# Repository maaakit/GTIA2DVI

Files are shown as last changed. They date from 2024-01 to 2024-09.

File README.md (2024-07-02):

# GTIA2DVI

**GTIA2DVI** jest prototypem urządzenia umożliwiającego wyświetlanie obrazu cyfrowego w standardzie DVI przez
ośmiobitowe komputery Atari. Komputery te były produkowane w czasach gdy telewizja cyfrowa nie była publicznie dostępna 
przez co są zdolne generowac obraz jedynie w analogowych systemach PAL / NTSC. Większośc nowych telewizorów nie jest 
w stanie wyświetlić obrazu generowaniego przez Atari w zadowalającej jakosci.
Powstało wiele urządzeń oraz modów toru video Atari w mniejszym lub większym stopniu poprawiajacych jakość obrazu.
Jednak wszystkie te rozwiązania polegaja na zmianie parametrów obrazu analogowego a następnie jego digitalizację i 
konwersję do obrazu cyfrowego.

Ten projekt jest próbą rozwiązania problemu w pełni w domenie cyfrowej. Sercem projektu jest mikrokontroler RP2040 i biblioteka [PicoDVI](https://github.com/Wren6991/PicoDVI) dzięki której może on generować obraz DVI. GTIA2DVI w sposób software'owy ale z wykorzystaniem udostępnianego przez
RP2040 hardweru tj: DMA, PIO, Interpolator realizuje dekodowanie sygnałów generowanych przez Atari oraz tworzenie obrazu.

## Szczegóły techniczne

Obraz w komputerach Atari jest generowany przez układy specializowane ANTIC / GTIA. 
Ten drugi układ jest odpowiedzialny z generowanie sygnałów które są następnie przetwarzane przez układy analogowe
w obraz w systemie PAL/NTSC. Z dostępnych w internecie materiałów można wywnioskować że wszystkie sygnały wyjściowe GTIA
składające się na obraz wideo na pinach tego układu są cyfrowe. Są to następujące:

| nazwa sygnału | pin GTIA | opis |
|---|---|---|
| OSC | 28 | sygnał zegarowy synchronizujący pixele w trybie hires |
| CSYNC | 25 | sygnał synchronizacji pionowej i poziomej |
| LUM0 - LUM3 | 31,22,23,24 | 4-bitowy równoległa linia prezentująca wartość jasności pixela |
| PAL | 16 | sygnał zegara odpowiadającego za kodowanie koloru w systemie PAL |
| COLOR | 21 | wartość koloru okreeślona przez przesunięcie fazowe tego sygnału względem PAL |

Celem projektu jest generowanie obrazu cyfrowego na podstawie wyżej wymienionych sygnałów.

## Budowanie projektu

Należy mieć skonfigurowane środowisko SDK dla RP2040 (patrz https://datasheets.raspberrypi.com/pico/getting-started-with-pico.pdf)

Projekt mozna zbudwać posługując się IDE (np. Visual Studio Code)

lub z linii komend:

```shell

cd software
mkdir build
cd build
cmake -DCMAKE_BUILD_TYPE=Release ..
make

```

Wynikiem procesu budowania jest plik: `build/gtia2dvi/gtia2dvi.uf2` który nalezy wgrać do RP2040.

Uwaga! Jedynie plik zbudowane w `BUILD_TYPE=Release` zapewniają poprawne działanie programu

## Uruchomienie

Po zamontowaniu urządzenia w Atari sygnał DVI będzie dostępny automatycznie. W podstawowej konfiguracji generowany jest 
sygnał monochroamtyczny w odcieniach szarości. 
Dekodowanie sygnału **chroma** jest w fazie eksperymentalnej i może zostać włączone z poziomu menu po uprzednim skalibrowaniu.

Urządzenie posiada 3 przyciski:

* **RESET** służący do resetowania
* **BTN_A** słuzący do aktywacji menu podczas restartu oraz do wybierania opcji menu. Poza menu przełącza tryb wyświetlania mono / color
* **BTN_B** służacy do aktywacji wybranej opcj menu. Poza menu pełni funkcję stopklatki (zatrzymuje odświerzanie obrazu Atari)

Aby wejść do menu systemowego należy trzymac wciśnięty przycisk **BTN_A** w trakcie restartu urządzenia (za pomocą przycisku reset)

## Opcje menu

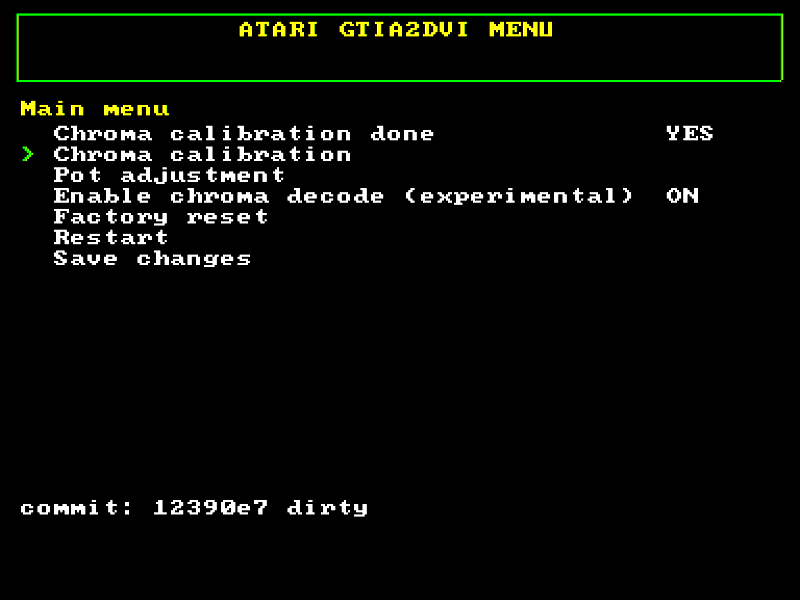
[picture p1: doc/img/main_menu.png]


* Informacja o statusie kalibracji
* [Kalibracja sygnału chroma](#kalibracja-sygnału-chroma)
* [Procedura ustawiania potencjometru CADJ](#ustawienie-potencjometru-CADJ)
* Włączanie / wyłączanie dekodowania
* Przywrócenie do ustawień fabrycznych
* Wyjście z menu i powrót do normalnego trybu
* Zapisanie wprowadzonych zmian

## Kalibracja sygnału chroma

Należy uruchomić Atari Basic i załadować program CALSCR którego listing znajduje się w folderze `atari`
Program wyświetla obraz służący do kalibracji. 

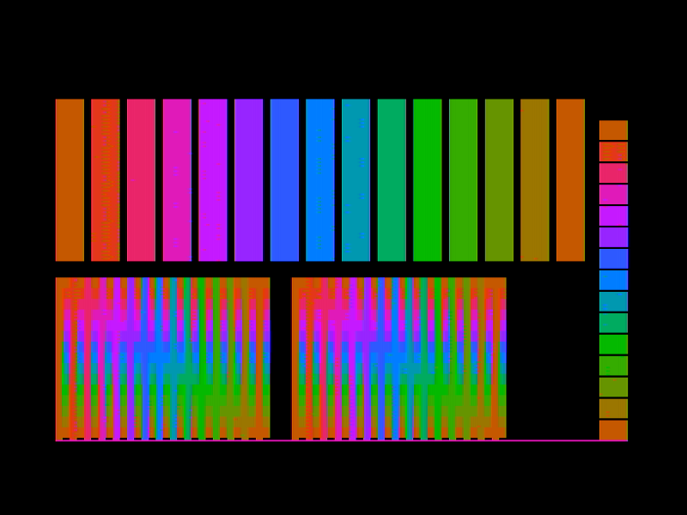
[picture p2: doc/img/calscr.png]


Gdy jego tworzenie zostanie zakończone należy przejść do menu GTIA2DVI.
Następnie wybrać opcję `Chroma Calibration` i ją potwierdzić.

W czasie kalibracji prezentowany jest na żywo aktualny postęp budowania mapy kolorów.
Proces składa się zdwóch przebiegów i trwa ok. 95 sekund. Po tym czasie urządzenie zapisze zarejestrowane mapy kolorów 
w automatycznie pamięci FLASH i automatycznie się zrestartuje.

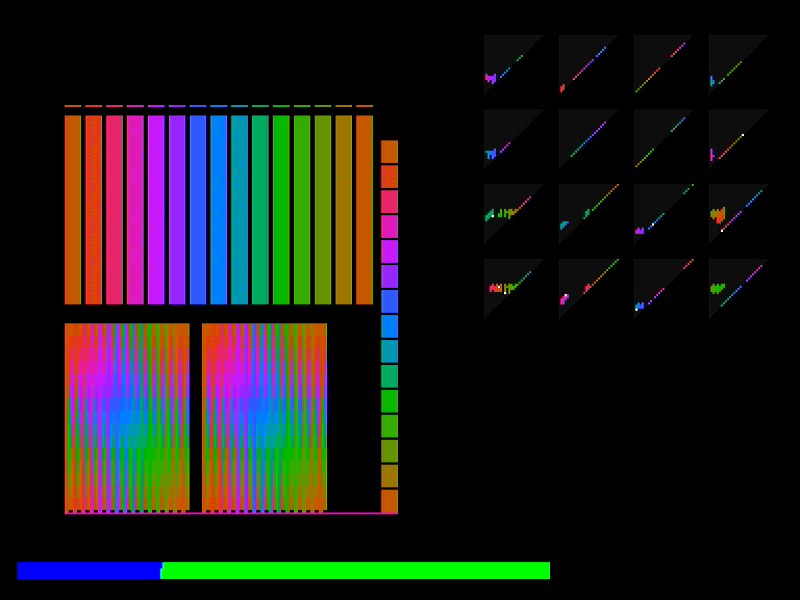
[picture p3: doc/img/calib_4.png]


## Ustawienie potencjometru CADJ

W pewnych przypadkach aby uzyskać dobry rezultat kalibracji niezbędne jest dostrojenie potencjometru CADJ.
W trakcie tego procesu Atari powinno wyświetlać ten sam obraz jak w procesie kalibracji (CALSCR).
Należy znaleźć takie położenie w którym na obrazie nie występują żółte kropki oraz ilość szarych jest jak najmniejsza.
Po zakończeniu regulacji należy przycisnąć RESET na płytce GTIA2DVI

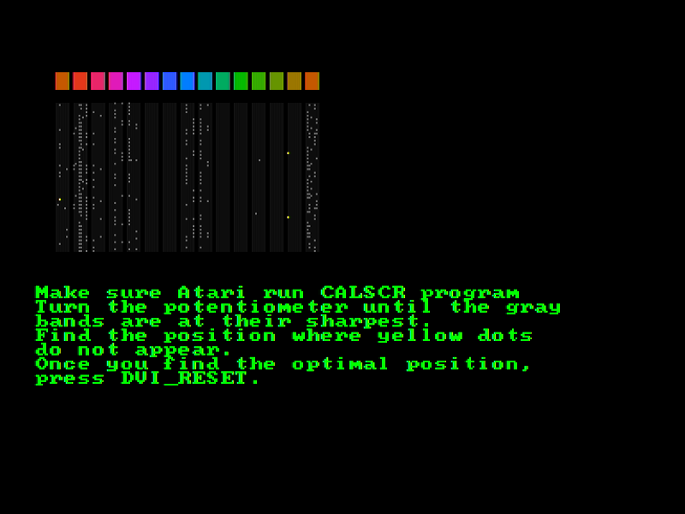
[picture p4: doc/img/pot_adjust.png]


## Dodatkowe wskazówki

Najlepszą jakość wyświetlanego koloru można osiągnąc na płytach które zapewniają niski poziom szumów i zakłóceń sygnałów.
Dodatkowe rozszerzenia np. U1MB, SIDE2 generują zauważalne zakłócenia w wyświetlanym kolorze
Pozytywny wpływ na generowany obraz mogą mieć:
* Zamiana dławika L37 na rezystor 470ohm
* Wymiana kondensatora C50 na nowy o niskim ESR
* Wymina potencjometru CADJ (R38) na precyzyjny wieloobrotowy
* zastosowanie Static RAM (niezweryfikowane)

## Troubleshooting

1) **Obraz DVI nie jest wyświetlany** należy:
   * wyłączyć Atari i zdemontowac GTIA2DVI
   * zweryfikować wszystkie połączenia
   * wgrać jeden z przykładowych programów z repozytorium PicoDVI (https://github.com/Wren6991/PicoDVI)

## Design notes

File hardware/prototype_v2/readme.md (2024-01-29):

# Lista elementów

| symbol | nazwa | wartość |
|---|---|---|
| C1 - C3  | kondensator | 100nF |
| R1 - R8  | rezystor | 270R |
| R9 - R14 | nie montować | |
| X1 | Raspberry Pi Pico | |
| IC2 | 74AC541 | |
| IC4P | podstawka 40pin | |
| IC5P | pin header 2x20 | |
| DVI | złącze DVI lub kompatybilne | |
| SWITCH | 3 mikrowłączniki do masy | |

## procedura pierwszego uruchomiania

1) Po zmontowaniu zweryfikować wszystkie połączenia
2) Nie montować GTIA i nie umieszczać modułu na płycie Atari
3) Podpiąć kablem usb do PC trzymając wciśnięty przycisk BOOTSEL
4) wgrać wsad gtia2dvi.uf2
5) podłączyć kablem do TV/monitora i uruchomić menu konfiguracyjne (trzymahąc wciśnięty BTN_A zresetowac moduł)
6) po prawidłowym zweryfikowaniu wyświetlanego obrazu odłączyć wszystkie połączenia
7) zamontować GTIA
8) podłączyć do płyty Atari
9) zweryfikować połączenia i uruchomić Atari

**Uwaga !**
To jest urządzenie DIY. Sam odpowiadasz za jego prawidłowe zmontowanie, uruchomienie i wszystkie szkody które może wyrządzić!

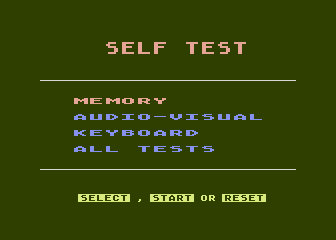
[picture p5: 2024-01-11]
software/gtia2dvi/images/atari001.png

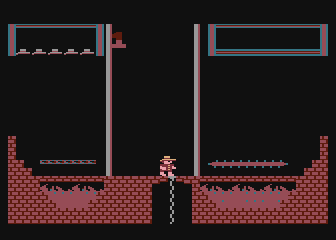
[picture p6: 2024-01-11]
software/gtia2dvi/images/atari003.png

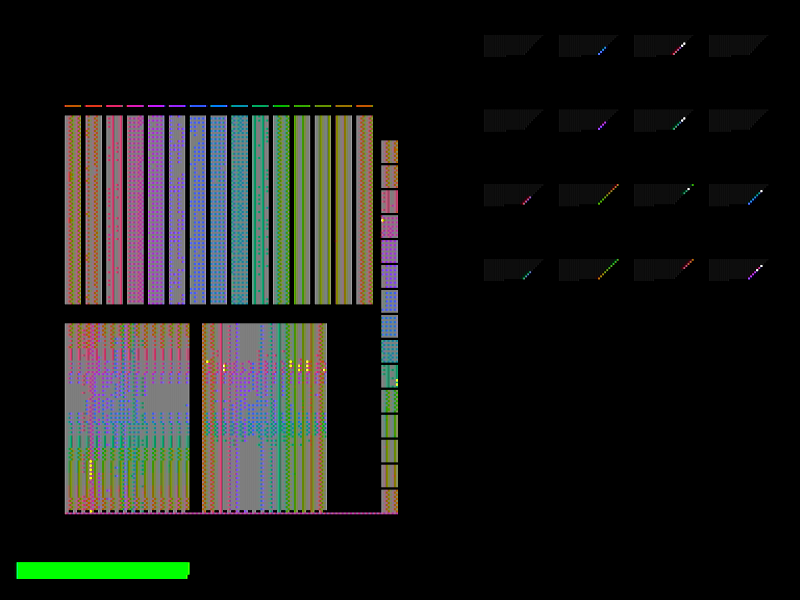
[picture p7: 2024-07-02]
doc/img/calib_2.png

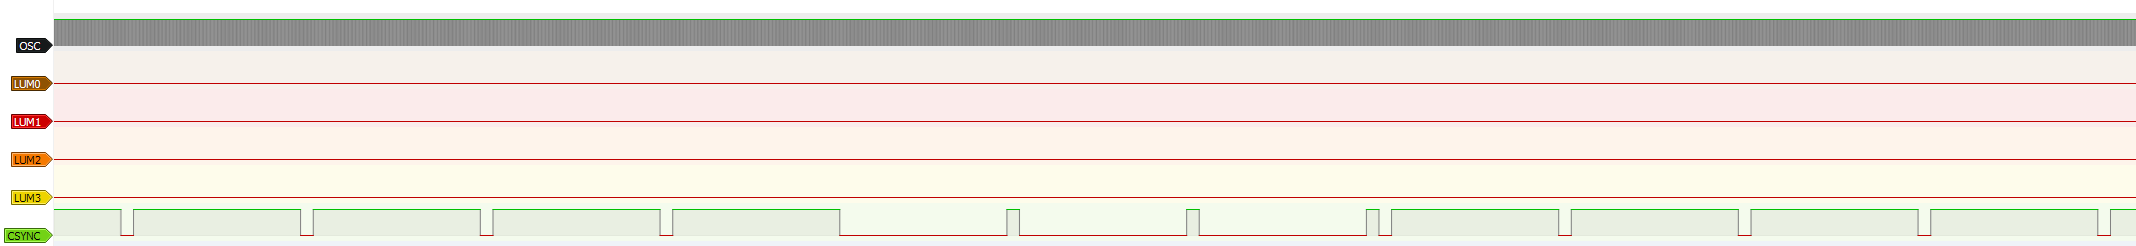
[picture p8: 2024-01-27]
luma_signals.png

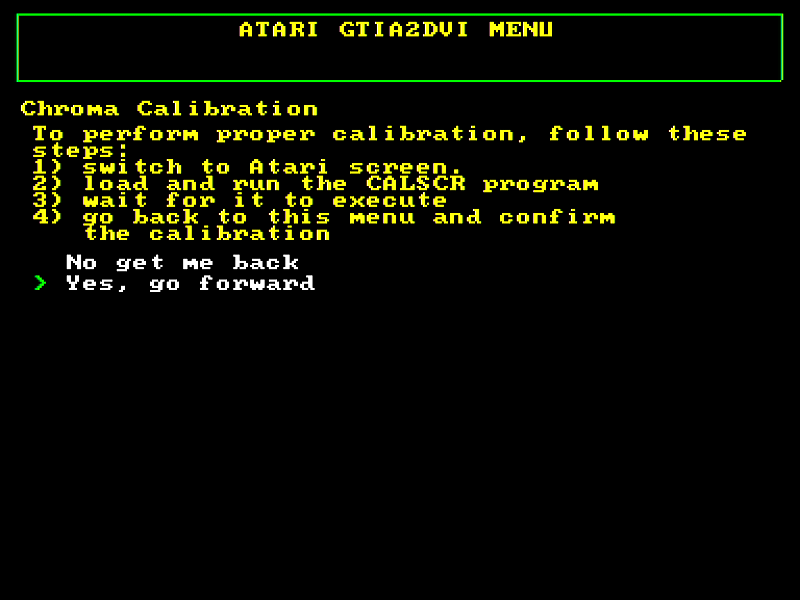
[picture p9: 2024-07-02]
doc/img/calib_confirm.png

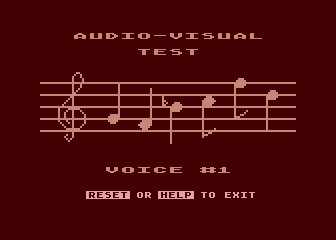
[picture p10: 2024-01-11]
software/gtia2dvi/images/atari002.png

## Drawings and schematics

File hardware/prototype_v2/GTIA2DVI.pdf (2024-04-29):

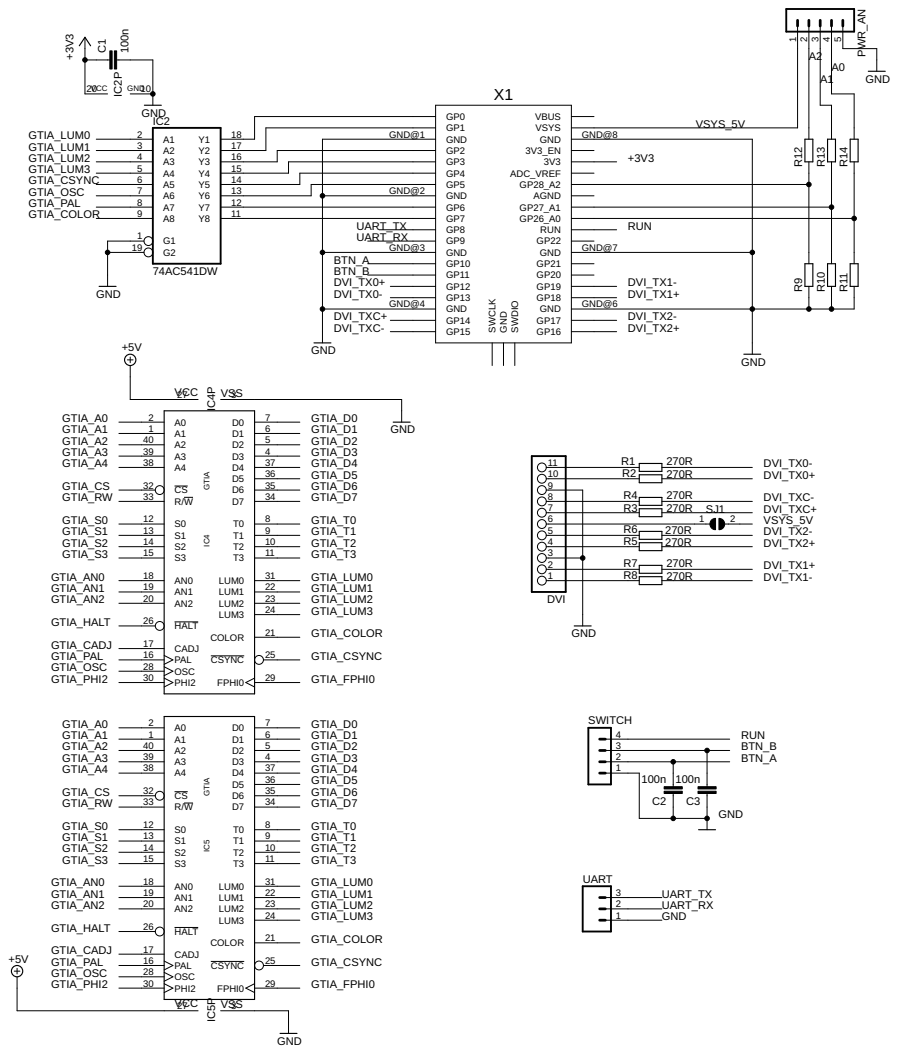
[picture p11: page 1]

UART_TX UART_RX | RUN

BTN_A BTN_B DVI_TX0+ DVI_TX0- | DVI_TX1-DVI_TX1+

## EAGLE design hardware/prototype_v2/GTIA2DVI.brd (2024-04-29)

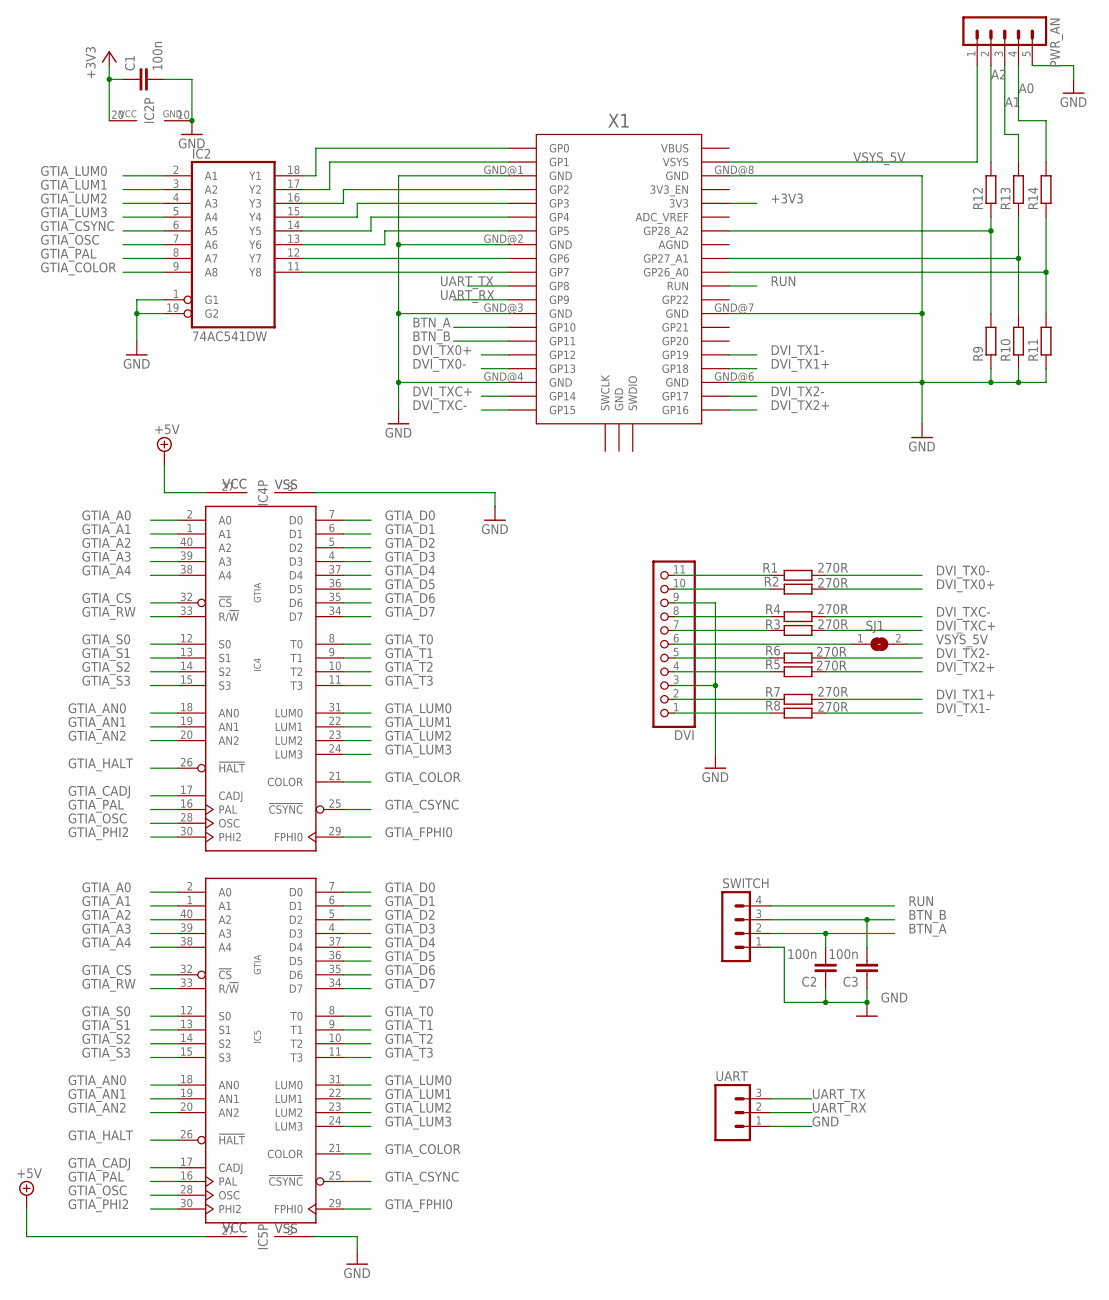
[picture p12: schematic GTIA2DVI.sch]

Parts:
C1, C2, C3: 100n; C0805
DVI: PINHD-1X11; 1X11
IC2: 74AC541DW; SO20W
IC4, IC5: GTIA; DIL40
PWR_AN: MA05-1
R1, R2, R3, R4, R5, R6, R7, R8: 270R; M0805
R9, R10, R11, R12, R13, R14: R-EU_M0805; M0805
SJ1: SJ
SWITCH: MA04-1
UART: MA03; 03P
X1: RPI_PICO_IG-TH; RPI_PICO_TH

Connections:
+3V3: C1.1, IC2.20 (VCC), X1.3V3
+5V: IC4.27 (VCC), IC5.27 (VCC)
A0: PWR_AN.4, R14.2
A1: PWR_AN.3, R13.2
A2: PWR_AN.2, R12.2
BTN_A: C2.2, SWITCH.2, X1.GP10
BTN_B: C3.2, SWITCH.3, X1.GP11
DVI_TX0+: R2.2, X1.GP12
DVI_TX0-: R1.2, X1.GP13
DVI_TX1+: R7.2, X1.GP18
DVI_TX1-: R8.2, X1.GP19
DVI_TX2+: R5.2, X1.GP16
DVI_TX2-: R6.2, X1.GP17
DVI_TXC+: R3.2, X1.GP14
DVI_TXC-: R4.2, X1.GP15
GND: C1.2, C2.1, C3.1, DVI.3, DVI.9, IC2.1 (G1), IC2.10 (GND), IC2.19 (G2), IC4.3 (VSS), IC5.3 (VSS), PWR_AN.5, R9.1, R10.1, R11.1, SWITCH.1, UART.1, X1.GND@1 (GND), X1.GND@2 (GND), X1.GND@3 (GND), X1.GND@4 (GND), X1.GND@6 (GND), X1.GND@7 (GND), X1.GND@8 (GND)
GP0: IC2.18 (Y1), X1.GP0
GP1: IC2.17 (Y2), X1.GP1
GP2: IC2.16 (Y3), X1.GP2
GP3: IC2.15 (Y4), X1.GP3
GP4: IC2.14 (Y5), X1.GP4
GP5: IC2.13 (Y6), X1.GP5
GP6: IC2.12 (Y7), X1.GP6
GP7: IC2.11 (Y8), X1.GP7
GTIA_A0: IC4.2 (A0), IC5.2 (A0)
GTIA_A1: IC4.1 (A1), IC5.1 (A1)
GTIA_A2: IC4.40 (A2), IC5.40 (A2)
GTIA_A3: IC4.39 (A3), IC5.39 (A3)
GTIA_A4: IC4.38 (A4), IC5.38 (A4)
GTIA_AN0: IC4.18 (AN0), IC5.18 (AN0)
GTIA_AN1: IC4.19 (AN1), IC5.19 (AN1)
GTIA_AN2: IC4.20 (AN2), IC5.20 (AN2)
GTIA_CADJ: IC4.17 (CADJ), IC5.17 (CADJ)
GTIA_COLOR: IC2.9 (A8), IC4.21 (COLOR), IC5.21 (COLOR)
GTIA_CS: IC4.32 (!CS), IC5.32 (!CS)
GTIA_CSYNC: IC2.6 (A5), IC4.25 (!CSYNC), IC5.25 (!CSYNC)
GTIA_D0: IC4.7 (D0), IC5.7 (D0)
GTIA_D1: IC4.6 (D1), IC5.6 (D1)
GTIA_D2: IC4.5 (D2), IC5.5 (D2)
GTIA_D3: IC4.4 (D3), IC5.4 (D3)
GTIA_D4: IC4.37 (D4), IC5.37 (D4)
GTIA_D5: IC4.36 (D5), IC5.36 (D5)
GTIA_D6: IC4.35 (D6), IC5.35 (D6)
GTIA_D7: IC4.34 (D7), IC5.34 (D7)
GTIA_FPHI0: IC4.29 (FPHI0), IC5.29 (FPHI0)
GTIA_HALT: IC4.26 (!HALT), IC5.26 (!HALT)
GTIA_LUM0: IC2.2 (A1), IC4.31 (LUM0), IC5.31 (LUM0)
GTIA_LUM1: IC2.3 (A2), IC4.22 (LUM1), IC5.22 (LUM1)
GTIA_LUM2: IC2.4 (A3), IC4.23 (LUM2), IC5.23 (LUM2)
GTIA_LUM3: IC2.5 (A4), IC4.24 (LUM3), IC5.24 (LUM3)
GTIA_OSC: IC2.7 (A6), IC4.28 (OSC), IC5.28 (OSC)
GTIA_PAL: IC2.8 (A7), IC4.16 (PAL), IC5.16 (PAL)
GTIA_PHI2: IC4.30 (PHI2), IC5.30 (PHI2)
GTIA_RW: IC4.33 (R/!W), IC5.33 (R/!W)
GTIA_S0: IC4.12 (S0), IC5.12 (S0)
GTIA_S1: IC4.13 (S1), IC5.13 (S1)
GTIA_S2: IC4.14 (S2), IC5.14 (S2)
GTIA_S3: IC4.15 (S3), IC5.15 (S3)
GTIA_T0: IC4.8 (T0), IC5.8 (T0)
GTIA_T1: IC4.9 (T1), IC5.9 (T1)
GTIA_T2: IC4.10 (T2), IC5.10 (T2)
GTIA_T3: IC4.11 (T3), IC5.11 (T3)
unnamed: DVI.11, R1.1
unnamed: DVI.10, R2.1
unnamed: DVI.8, R4.1
unnamed: DVI.7, R3.1
unnamed: DVI.5, R6.1
unnamed: DVI.4, R5.1
unnamed: DVI.2, R7.1
unnamed: DVI.1, R8.1
unnamed: R9.2, R12.1, X1.GP28_A2
unnamed: R10.2, R13.1, X1.GP27_A1
unnamed: R11.2, R14.1, X1.GP26_A0
RUN: SWITCH.4, X1.RUN
UART_RX: UART.2, X1.GP9
UART_TX: UART.3, X1.GP8
VSYS_5V: DVI.6, PWR_AN.1, SJ1.1, SJ1.2, X1.VSYS

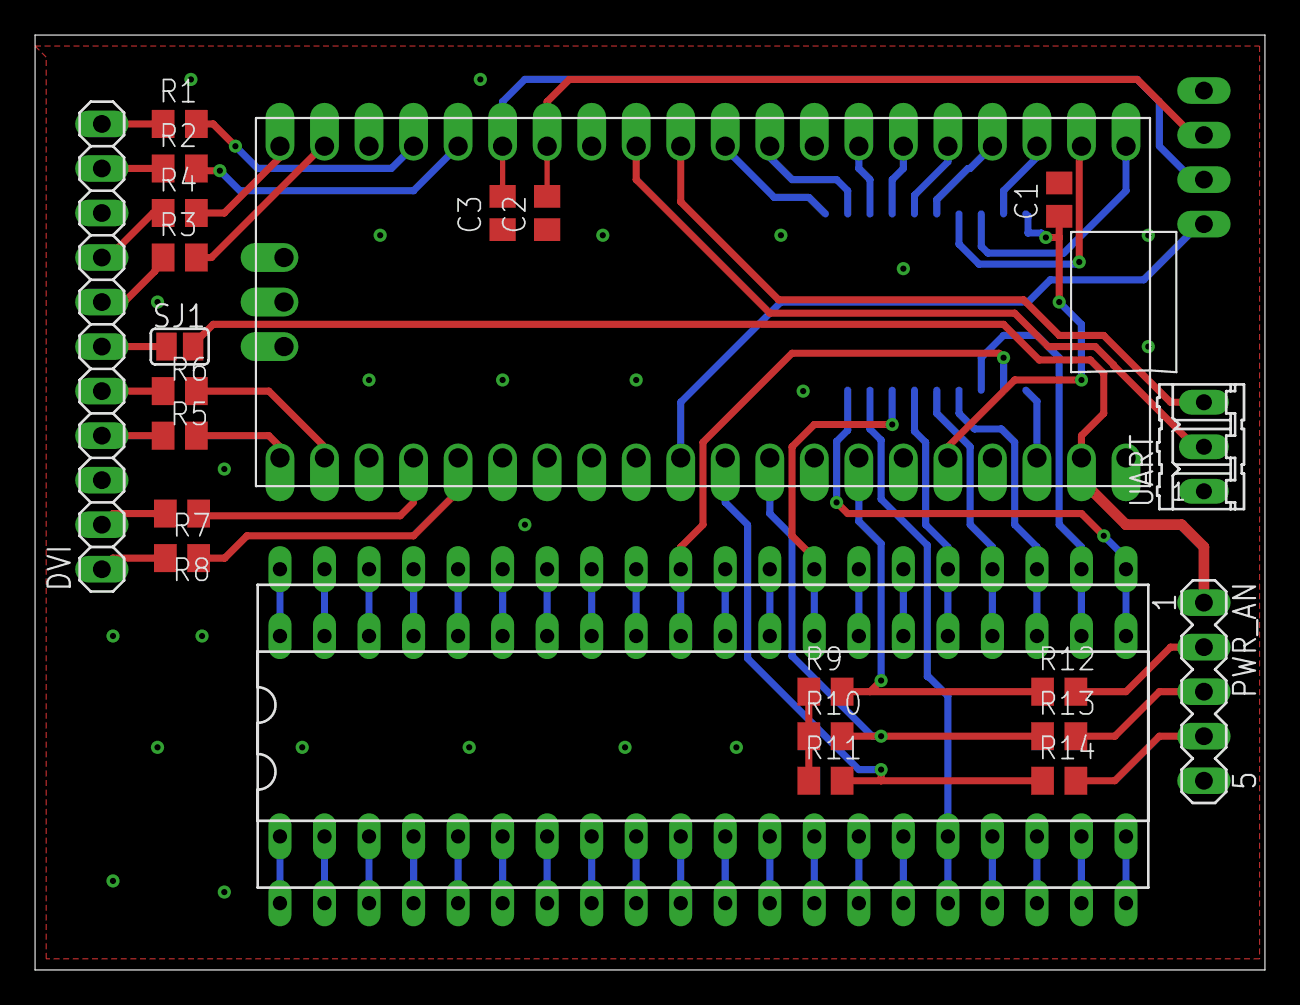
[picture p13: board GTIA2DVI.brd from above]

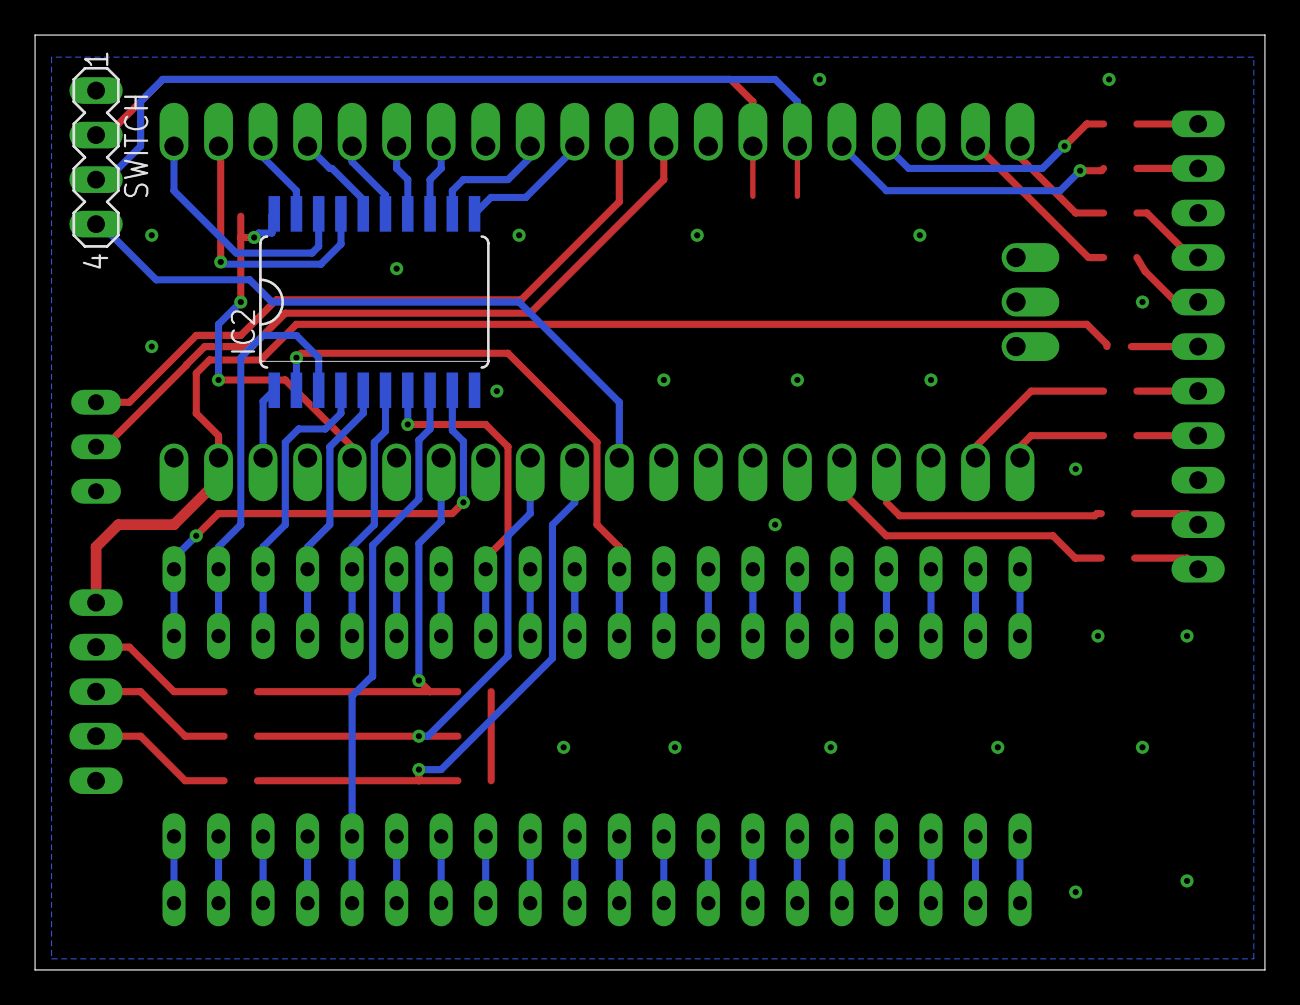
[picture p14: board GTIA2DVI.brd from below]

Board: 2 copper layers, 70.2 x 53.3 mm, 26 parts (2 on the bottom side), 77 nets.

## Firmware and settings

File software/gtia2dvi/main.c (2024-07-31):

#include "pico/stdlib.h"
#include "hardware/vreg.h"
#include "cfg.h"
#include "gfx/font8x8.h"
#include "gfx/gfx.h"
#include "util/flash_storage.h"
#include "dvi_display.h"
#include "video_channel.h"
#include "util/buttons.h"
#include "ui/app_menu.h"
#include "util/post_boot.h"
#include "util/uart_log.h"
#include "gtia_dump.h"
#include "git_info.h"
#include "gtia_pal_gen.pio.h"

int main()
{
	gpio_init(LED_PIN);
	gpio_set_dir(LED_PIN, GPIO_OUT);

	uart_log_init();
	uart_log_putln("");
	uart_log_putln("/---------------\\");
	uart_log_putln("| GTIA2DVI_PICO |");
	uart_log_putln("\\---------------/");
	uart_log_putln(get_commit_info(buf, 128));
	uart_log_putln("starting");
	uart_log_putln("about to exec post boot action");
	uart_log_flush_blocking();

	exec_post_boot_action();

	btn_init();

	sleep_ms(10);

	if (gtia_dump_is_requested() || GTIA_DUMP_FORCE)
	{
		uart_log_putln("GTIA DUMP mode requested");
		uart_log_flush_blocking();
		gtia_dump_process();
	}

	bool menu_requested = btn_is_down(BTN_A);

	if (flash_config_saved())
	{
		uart_log_putln("config loaded");
		flash_load_config(&app_cfg);
		cfg_log_to_uart();
	}
	else
	{
		uart_log_putln("using default config");
		cfg_init();
		cfg_log_to_uart();
	}

	if (flash_preset_saved())
	{
		uart_log_putln("preset loaded");
		flash_load_preset((uint8_t *)calibration_data);
		preset_loaded = true;
	}
	else
	{
		uart_log_putln("preset not loaded");
		app_cfg.enableChroma = false;
	}

	uart_log_flush_blocking();

	sleep_ms(200);
	vreg_set_voltage(VREG_VSEL);
	sleep_ms(200);

	uart_log_putln("about to start dvi infrastructure");
	uart_log_flush_blocking();

	sleep_ms(100);
	setup_display();


	 uint o = pio_add_program(pio0, &gtia_pal_gen_program);
     gtia_pal_gen_program_init(pio0, 3, o);

	if (menu_requested || FORCE_MENU)
	{
		uart_log_putln("entering menu");
		uart_log_flush_blocking();
		main_menu_show();
	}

	uart_log_putln("about to start gtia video stream");
	uart_log_flush_blocking();
	process_video_stream();

	__builtin_unreachable();
}

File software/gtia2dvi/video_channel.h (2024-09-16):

#include "gtia_luma_ng.pio.h"
#include "gtia_chroma_ng.pio.h"
#include "gtia_palette.h"
#include "util/buttons.h"
#include "util/uart_log.h"
#include "chroma_calibration.h"
#include "burst.h"

#ifndef VIDEO_CHANNEL_H
#define VIDEO_CHANNEL_H

#define GTIA_PIO pio1
#define GTIA_LUMA_SM 0
#define GTIA_COLOR_SM 1

#define LUMA_DMA_CHANNEL 10
#define CHROMA_DMA_CHANNEL 11
#define LUMA_LINE_LENGTH_BYTES 206

#define LUMA_START_OFFSET 12

uint16_t luma_buf[LUMA_LINE_LENGTH_BYTES / 2];

static inline void _setup_gtia_interface()
{
    gpio_init_mask(INPUT_PINS_MASK);
    gpio_set_dir_in_masked(INPUT_PINS_MASK);

    dma_channel_config c = dma_channel_get_default_config(LUMA_DMA_CHANNEL);
    channel_config_set_transfer_data_size(&c, DMA_SIZE_32);
    channel_config_set_dreq(&c, pio_get_dreq(GTIA_PIO, GTIA_LUMA_SM, false));
    channel_config_set_read_increment(&c, false);
    channel_config_set_write_increment(&c, true);
    dma_channel_configure(LUMA_DMA_CHANNEL, &c, &luma_buf, &GTIA_PIO->rxf[GTIA_LUMA_SM], (LUMA_LINE_LENGTH_BYTES + 2) / 4, false);

    dma_channel_config c2 = dma_channel_get_default_config(CHROMA_DMA_CHANNEL);
    channel_config_set_transfer_data_size(&c2, DMA_SIZE_32);
    channel_config_set_dreq(&c2, pio_get_dreq(pio1, GTIA_COLOR_SM, false));
    channel_config_set_read_increment(&c2, false);
    channel_config_set_write_increment(&c2, true);
    dma_channel_configure(CHROMA_DMA_CHANNEL, &c2, &chroma_buf, &GTIA_PIO->rxf[GTIA_COLOR_SM], CHROMA_LINE_LENGTH, false);

    pio_sm_restart(GTIA_PIO, GTIA_LUMA_SM);
    pio_sm_restart(GTIA_PIO, GTIA_COLOR_SM);
    uint offset_lm = pio_add_program(GTIA_PIO, &gtia_luma_ng_program);
    uint offset_ch = pio_add_program(GTIA_PIO, &gtia_chroma_ng_program);
    gtia_chroma_ng_program_init(GTIA_COLOR_SM, offset_ch, CHROMA_LINE_LENGTH);
    gtia_luma_ng_program_init(GTIA_PIO, GTIA_LUMA_SM, offset_lm, LUMA_LINE_LENGTH_BYTES);

    burst_init();
}

static inline void _wait_and_restart_dma(int prev_row)
{

    if (prev_row == 307)
    {
        //  pio_sm_restart(GTIA_PIO, BURST_SM);
        pio_sm_restart(GTIA_PIO, BURST_SM);
        pio_sm_clear_fifos(GTIA_PIO, BURST_SM);

        pio_sm_exec(GTIA_PIO, BURST_SM, pio_encode_jmp(offset_burst_prg));
        dma_channel_set_write_addr(BURST_DMA_CHANNEL, &burst_data, true);
        pio_sm_set_enabled(GTIA_PIO, BURST_SM, true);
    }
    else
    {
        pio_sm_set_enabled(GTIA_PIO, BURST_SM, false);
    }

    // wait for both DMA channels
    dma_channel_wait_for_finish_blocking(LUMA_DMA_CHANNEL);
    dma_channel_wait_for_finish_blocking(CHROMA_DMA_CHANNEL);
    // restart DMA channels
    dma_channel_set_write_addr(CHROMA_DMA_CHANNEL, &chroma_buf[buf_seq], true);
    dma_channel_set_write_addr(LUMA_DMA_CHANNEL, &luma_buf, true);
    // dma_channel_set_write_addr(BURST_DMA_CHANNEL, &burst_data, true);

    buf_seq = (buf_seq + 1) % 2;
}

#ifdef DUMP_PIXEL_FEATURE_ENABLED
uint16_t pxl_dump_pos_x = 0, pxl_dump_pos_y = 0;
char cmd = 0;

#define DUMP_PIXEL_DATA_IF_MATCH(X)                                                                                        \
    if (pixel_ptr == pixel_catch_ptr)                                                                                      \
    sprintf(buf, "%1d pos: %03d,%03d lu: %02d i: %03d pa: %08x co: %08x / %08x -> %d/%d [%d,%d]",                          \
            (X) / 4, pxl_dump_pos_x, pxl_dump_pos_y, _get_current_luma(INTERP0_LUMA_SHIFT(X)), pal_ptr - pal_buf[buf_seq], \
            *pal_ptr, *color_ptr, *(color_ptr + 1), match_color(*color_ptr, *pal_ptr, row), match_color(*(color_ptr + 1), *(pal_ptr + 1), row), decode(*color_ptr, *pal_ptr) & 0x1f, (decode(*color_ptr, *pal_ptr) >> 5) & 0x1f)

/*
    dumps to UART console debug data describing single pixel pointed by user.
    pointed pixel is display as red dot that can be moved with UART console with numeric keys:
    4 for left direction
    8 for up direction
    6 for right direction
    2 for down
    5 triggers data to be writen to UART
*/
static void __not_in_flash_func(_locate_and_dump_pixel_data)(uint16_t row)
{
    uint32_t y = row - FIRST_GTIA_ROW_TO_SHOW + SCREEN_OFFSET_Y;
    uint16_t *pixel_ptr = framebuf + y * FRAME_WIDTH + SCREEN_OFFSET_X;
    uint16_t *pixel_catch_ptr = pixel_ptr + pxl_dump_pos_x - LUMA_START_OFFSET - 2;
    uint32_t *color_ptr = color_buf[buf_seq];
    uint32_t *pal_ptr = pal_buf[buf_seq];

    color_ptr += CHROMA_START_OFFSET;
    pal_ptr += CHROMA_START_OFFSET;

    for (uint32_t i = LUMA_START_OFFSET; i < (LUMA_LINE_LENGTH_BYTES / 2) - LUMA_WORDS_TO_SKIP; i++)
    {
        uint32_t luma_4px = luma_buf[i];
        interp0->accum[1] = luma_4px << 1;

        // first luma (hires) pixel
        DUMP_PIXEL_DATA_IF_MATCH(0);
        *pixel_ptr++ = BLACK;

        color_ptr++;
        pal_ptr++;

        // second luma (hires) pixel
        DUMP_PIXEL_DATA_IF_MATCH(4);
        *pixel_ptr++ = BLACK;

        // third luma (hires) pixel
        DUMP_PIXEL_DATA_IF_MATCH(8);
        *pixel_ptr++ = BLACK;

        // move to next chroma pixel
        color_ptr++;
        pal_ptr++;

        // forth luma (hires) pixel
        DUMP_PIXEL_DATA_IF_MATCH(12);
        *pixel_ptr++ = BLACK;
    }
    uart_log_putln(buf);
    cmd = 0;
}
#endif

static inline int8_t match_color(const uint32_t *chromabuf, const int8_t (*calib_data_ptr)[4][2048])
{
    uint32_t sample = *chromabuf;
    int dec = decode_intr(sample);
    // requires chromabuf to be 16 bytes aligned!
    int col = (*calib_data_ptr)[((int)chromabuf >> 2) & 0x03][dec];
    if (col < 0)
        col = 0;
    return col;
}

static void __no_inline_not_in_flash_func(_draw_luma_and_chroma_row)(uint32_t row)
{
    const uint16_t dvi_y = row - FIRST_GTIA_ROW_TO_SHOW + SCREEN_OFFSET_Y;

    if (dvi_y == scanline || dvi_y + 1 == scanline)
    {
        // don't modify line which is currently transferred to TDMS pipeline
        return;
    }

    const uint cpos = app_cfg.chroma_calib_offset - 8;
    const int8_t(*calib_data_ptr)[4][2048] = &calibration_data[row % 2];

    int gtia_color = 0;
    uint dvi_x = SCREEN_OFFSET_X;
    uint32_t *chroma_buf_ptr = &chroma_buf[buf_seq][cpos];

    for (uint16_t i = LUMA_START_OFFSET; i < (LUMA_LINE_LENGTH_BYTES / 2); i++)
    {
        uint16_t luma4px = luma_buf[i];
        uint8_t pixel_luma = luma4px & 0xf;
        plotf(dvi_x++, dvi_y, gtia_color * 16 + pixel_luma);

        gtia_color = match_color(chroma_buf_ptr++, calib_data_ptr);
        pixel_luma = (luma4px >> 4) & 0xf;
        plotf(dvi_x++, dvi_y, gtia_color * 16 + pixel_luma);

        pixel_luma = (luma4px >> 8) & 0xf;
        plotf(dvi_x++, dvi_y, gtia_color * 16 + pixel_luma);

        gtia_color = match_color(chroma_buf_ptr++, calib_data_ptr);
        pixel_luma = (luma4px >> 12) & 0xf;
        plotf(dvi_x++, dvi_y, gtia_color * 16 + pixel_luma);
    }
}
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

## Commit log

2024-01-12 buttons and menu introduced
2024-01-15 [wip] luma calibration menu and others
2024-01-17 [wip] fixed all flash access problems
    [cfg.h, main.c]
2024-01-18 new resolution 768x576 50Hz
2024-01-18 screen parametrization; can switch chroma /luma only at runtime
2024-01-20 prompt before factory reset and chroma calibration
    [cfg.h, main.c, video_channel.h]
2024-01-23 more reliable and deterministic statisctcs driven calibration process
2024-01-24 uart_log introduced / code separated in folders
2024-01-25 uart logging added
2024-01-27 more logs / schematic added
    [GTIA2DVI.brd, GTIA2DVI.sch]
2024-01-27 added atari basic listings for calibration program
2024-01-27 prototype hwd folder renamed
    [GTIA2DVI.brd, GTIA2DVI.sch]
2024-02-11 uart output switched to gpio pin 21
2024-04-29 moved to hardware UART buttons and UART pins changed
    [GTIA2DVI.brd, GTIA2DVI.sch]
2024-04-29 core voltage decreased to 1.25V
2024-05-06 framebuffer chcanged from rgb565 to indexed 8b palette to save some RAM
2024-05-09 uart_log_flush moved to dvi core
2024-05-11 chroma calibration rewriten
2024-07-01 osc triggered chroma samples
2024-07-01 improved calibratoion - wip
2024-07-01 added calibration saving rewritten chroma and luma video display
2024-07-01 fixed problem in second phase of calibration
    [chroma_calibration.h, video_channel.h]
2024-07-01 pot adjustment procedure / calibration optimizations
2024-07-01 multithreading syncing in uart logger
2024-07-01 chroma calibration improvements
2024-07-01 config is logged to uart on boot
2024-07-01 extended mode for calibration step2
2024-07-01 new calibration screen
2024-07-01 actual git commit info in uart log, menu screen and filename
2024-07-01 Revert "new calibration screen"
    This reverts commit 95aed511
    [chroma_calibration.h]
2024-07-20 chroma sample size extended to 32b
2024-07-20 dump color mapping to uart and bigger diagram
2024-07-28 fixed error when wrong color wasdraw during calibration
    [chroma_calibration.h, chroma_map_diagram.h, uart_log.h]
2024-07-31 PAL clock generation on pin 22
2024-09-04 burst condition logged to uart
2024-09-16 fixed buttons software debouncing problem
    [chroma_calibration.h, video_channel.h]

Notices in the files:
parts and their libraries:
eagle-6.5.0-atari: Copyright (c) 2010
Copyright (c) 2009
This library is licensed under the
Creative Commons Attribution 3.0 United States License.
